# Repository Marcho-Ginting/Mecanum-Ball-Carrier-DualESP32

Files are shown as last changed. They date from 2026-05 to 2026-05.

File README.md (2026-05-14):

# Mecanum-Ball-Carrier-DualESP32

A high-performance mechatronic system utilizing omnidirectional locomotion and a distributed processing architecture for precision robotics tasks.

## 📊 Technical Specifications
* **Architecture:** Dual-ESP32 System (Distributed processing for control and feedback).
* **Locomotion:** 4-wheel drive using Mecanum wheels for 360-degree holonomic movement.
* **Actuation:** 4x High-torque Direct Drive actuators with integrated encoders.
* **PCB:** Custom-manufactured board for power distribution and encoder signal conditioning.

## ⚡ Engineering Highlights
* **Distributed Processing:** Implemented a Dual-ESP32 architecture to isolate real-time motor control and encoder processing from higher-level telemetry and communication, ensuring system stability.
* **Precision Motion Control:** Developed algorithms for Mecanum wheel kinematics, utilizing closed-loop encoder feedback to achieve high-precision velocity and positional tracking.
* **System Integration:** Engineered a custom PCB to consolidate four motor drivers and encoder inputs, optimizing signal integrity and reducing the mechanical footprint of the electronics.
* **Leadership:** Led a cross-disciplinary team of engineers, managing the full development lifecycle from component selection to final system debugging.

## 📂 Repository Structure
* `/logic`: Main logic digital board
* `/pdb`: Driver motor and power distribution board.

## 📷 3D KiCad Render Images

<table style="width:100%">
  <tr>
    <td align="center">
      <br/>
      <b>PDB</b>
    </td>
    <td align="center">
      <br/>
      <b>Logic</b>
    </td>
  </tr>
</table>

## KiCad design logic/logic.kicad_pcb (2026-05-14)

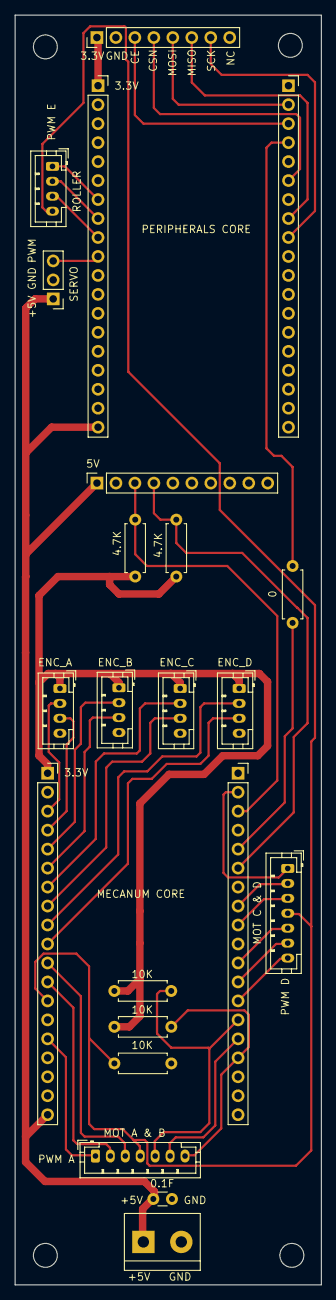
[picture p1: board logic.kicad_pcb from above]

Board: 2 copper layers, 41.0 x 170.0 mm, 22 parts (0 on the bottom side), 38 nets.

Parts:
C_BYPASS1: 0.1uF; C_Disc_D3.0mm_W1.6mm_P2.50mm
J_DRV_SIG1, J_DRV_SIG2: Conn_01x07; JST_PH_B7B-PH-K_1x07_P2.00mm_Vertical
J_DRV_SIG_1: Conn_01x04; JST_PH_B4B-PH-K_1x04_P2.00mm_Vertical
J_IMU1: Conn_01x10_Socket; PinSocket_1x10_P2.54mm_Vertical
J_LEFT_ENC1, J_LEFT_ENC2: Conn_01x04; JST_PH_B4B-PH-K_1x04_P2.00mm_Vertical
J_LEFT_HEADERS1, J_LEFT_HEADERS2: Conn_01x19_Pin; PinSocket_1x19_P2.54mm_Vertical
J_LOGIC1: Screw_Terminal_01x02; TerminalBlock_bornier-2_P5.08mm
J_RF1: Conn_01x08_Pin; PinHeader_1x08_P2.54mm_Vertical
J_RIGHT_ENC1, J_RIGHT_ENC2: Conn_01x04; JST_PH_B4B-PH-K_1x04_P2.00mm_Vertical
J_RIGHT_HEADERS1, J_RIGHT_HEADERS2: Conn_01x19_Pin; PinSocket_1x19_P2.54mm_Vertical
J_SERVO1: Conn_01x03_Pin; PinHeader_1x03_P2.54mm_Vertical
R_JUMPER1: 0; R_Axial_DIN0207_L6.3mm_D2.5mm_P7.62mm_Horizontal
R_PULLUP1, R_PULLUP2: 4.7K; R_Axial_DIN0207_L6.3mm_D2.5mm_P7.62mm_Horizontal
R_PULLUP3, R_PULLUP4, R_PULLUP5: 10K; R_Axial_DIN0207_L6.3mm_D2.5mm_P7.62mm_Horizontal

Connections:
/3.3V_MEC: J_LEFT_ENC1.1, J_LEFT_ENC2.1, J_LEFT_HEADERS1.1, J_RIGHT_ENC1.1, J_RIGHT_ENC2.1, R_PULLUP1.2, R_PULLUP2.2, R_PULLUP3.2, R_PULLUP5.2
/3.3V_PER: J_LEFT_HEADERS2.1, J_RF1.1
/+5V: C_BYPASS1.1, J_IMU1.1, J_LEFT_HEADERS1.19, J_LEFT_HEADERS2.19, J_LOGIC1.1, J_SERVO1.1
/CE: J_RF1.3, J_RIGHT_HEADERS2.3
/CSN: J_RF1.4, J_RIGHT_HEADERS2.6
/ENC_A1: J_LEFT_ENC1.2, J_LEFT_HEADERS1.3
/ENC_A2: J_LEFT_ENC1.3, J_LEFT_HEADERS1.4
/ENC_B1: J_LEFT_ENC2.2, J_LEFT_HEADERS1.5
/ENC_B2: J_LEFT_ENC2.3, J_LEFT_HEADERS1.6
/ENC_C1: J_LEFT_HEADERS1.7, J_RIGHT_ENC1.2
/ENC_C2: J_LEFT_HEADERS1.8, J_RIGHT_ENC1.3
/ENC_D1: J_LEFT_HEADERS1.9, J_RIGHT_ENC2.2
/ENC_D2: J_LEFT_HEADERS1.10, J_RIGHT_ENC2.3
/GND_LOGIC: C_BYPASS1.2, J_IMU1.2, J_LEFT_ENC1.4, J_LEFT_ENC2.4, J_LEFT_HEADERS1.14, J_LEFT_HEADERS2.14, J_LOGIC1.2, J_RF1.2, J_RIGHT_ENC1.4, J_RIGHT_ENC2.4, J_RIGHT_HEADERS1.1, J_RIGHT_HEADERS2.1, J_SERVO1.2, R_PULLUP4.2
/IN_A1: J_DRV_SIG1.3, J_LEFT_HEADERS1.11
/IN_A2: J_DRV_SIG1.2, J_LEFT_HEADERS1.12
/IN_B1: J_DRV_SIG1.5, J_RIGHT_HEADERS1.14, R_PULLUP3.1
/IN_B2: J_DRV_SIG1.6, J_RIGHT_HEADERS1.15
/IN_C1: J_DRV_SIG2.3, J_RIGHT_HEADERS1.9
/IN_C2: J_DRV_SIG2.2, J_RIGHT_HEADERS1.8
/IN_D1: J_DRV_SIG2.5, J_RIGHT_HEADERS1.11
/IN_D2: J_DRV_SIG2.6, J_RIGHT_HEADERS1.12
/IN_E1: J_DRV_SIG_1.3, J_LEFT_HEADERS2.9
/IN_E2: J_DRV_SIG_1.2, J_LEFT_HEADERS2.8
/MISO: J_RF1.6, J_RIGHT_HEADERS2.8
/MOSI: J_RF1.5, J_RIGHT_HEADERS2.2
/PWM_A: J_DRV_SIG1.1, J_LEFT_HEADERS1.15
/PWM_B: J_DRV_SIG1.7, J_RIGHT_HEADERS1.16, R_PULLUP5.1
/PWM_C: J_DRV_SIG2.1, J_RIGHT_HEADERS1.2
/PWM_D: J_DRV_SIG2.7, J_RIGHT_HEADERS1.13
/PWM_E: J_DRV_SIG_1.1, J_LEFT_HEADERS2.7
/PWM_SERVO: J_LEFT_HEADERS2.10, J_SERVO1.3
/SCK: J_RF1.7, J_RIGHT_HEADERS2.9
/SCL: J_IMU1.3, J_RIGHT_HEADERS1.3, R_PULLUP2.1
/SDA: J_IMU1.4, J_RIGHT_HEADERS1.6, R_PULLUP1.1
/STBY: J_DRV_SIG1.4, J_DRV_SIG2.4, J_DRV_SIG_1.4, J_LEFT_HEADERS1.13, R_PULLUP4.1
/UART_MASTER: J_RIGHT_HEADERS2.4, R_JUMPER1.1
/UART_SLAVE: J_RIGHT_HEADERS1.5, R_JUMPER1.2

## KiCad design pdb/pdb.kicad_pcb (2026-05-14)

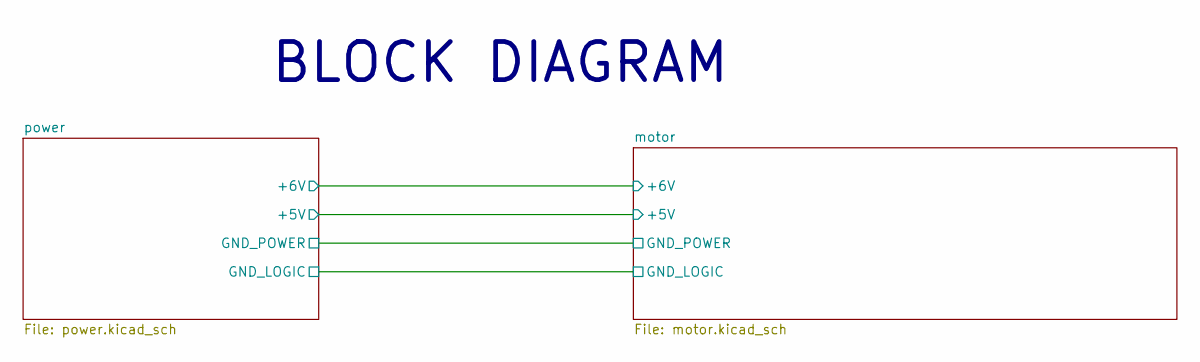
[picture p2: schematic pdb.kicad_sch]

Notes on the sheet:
BLOCK DIAGRAM

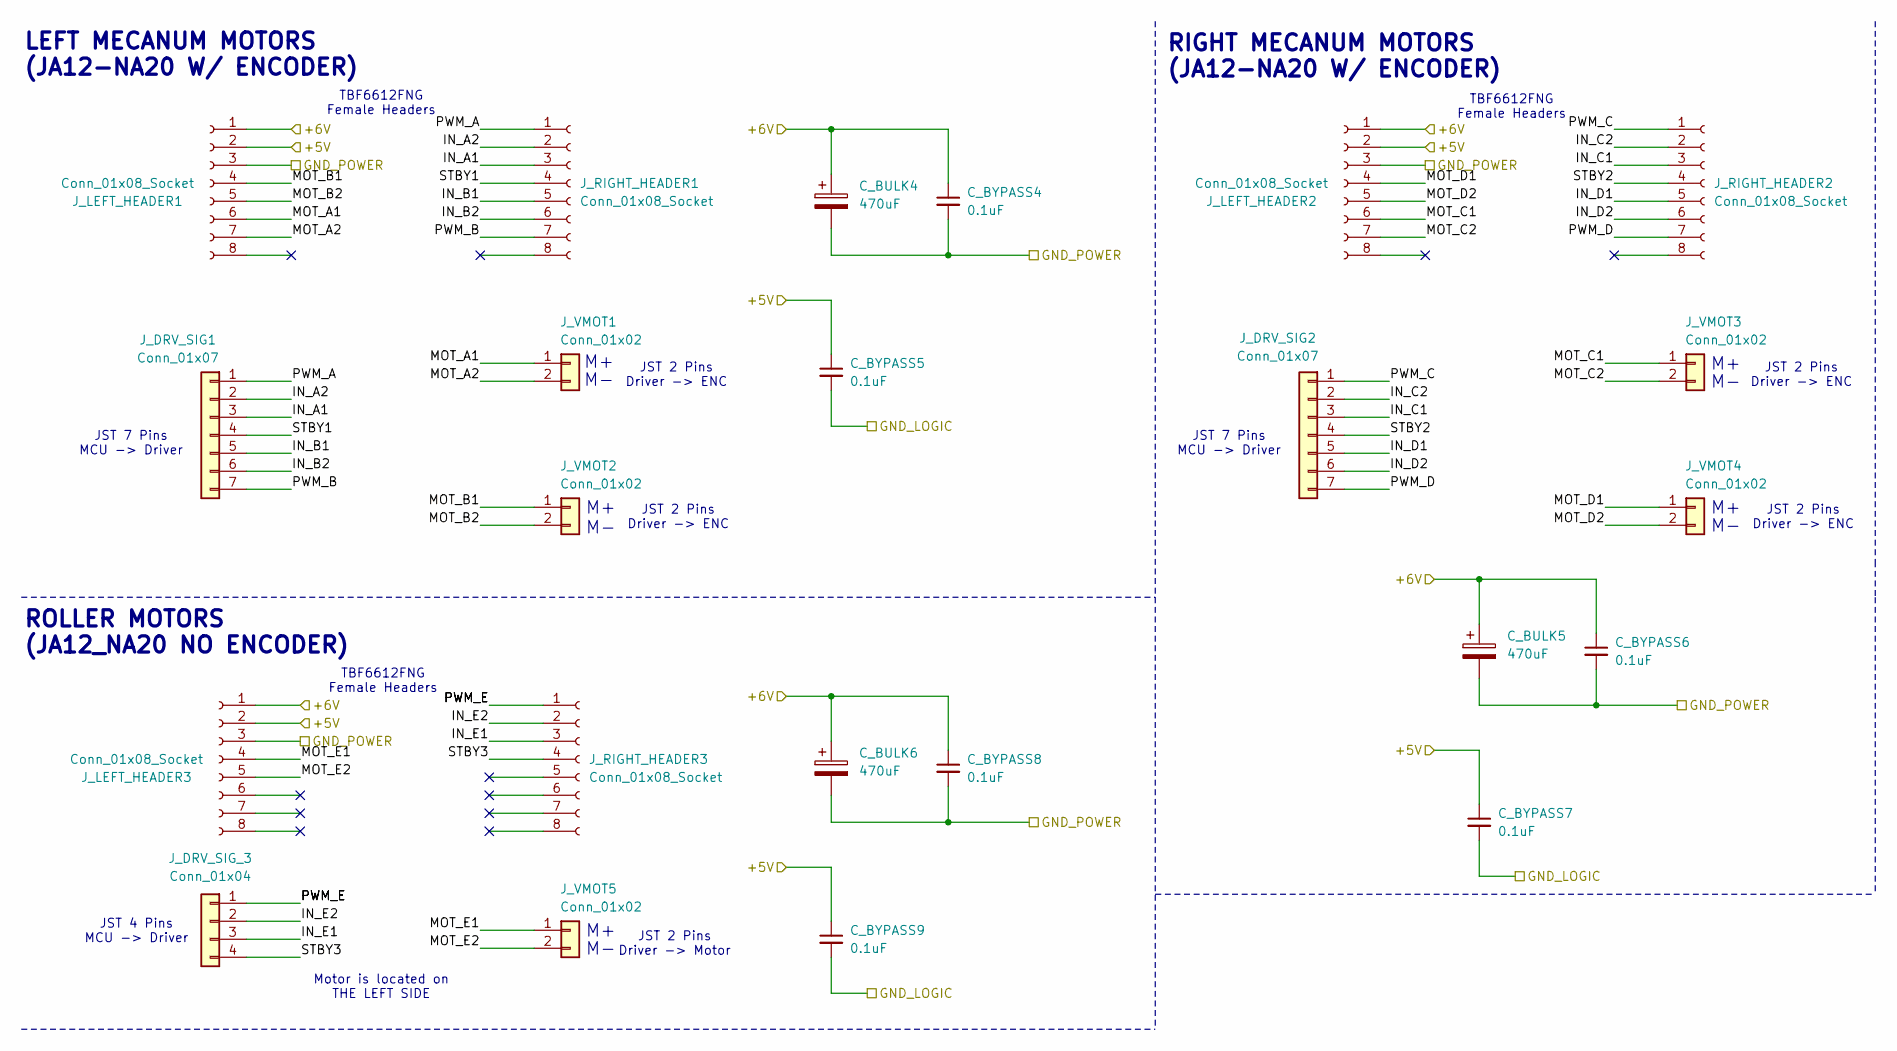
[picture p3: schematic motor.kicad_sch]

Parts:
C_BULK4, C_BULK5, C_BULK6: 470uF; CP_Radial_D10.0mm_P5.00mm
C_BYPASS4, C_BYPASS5, C_BYPASS6, C_BYPASS7, C_BYPASS8, C_BYPASS9: 0.1uF; C_Disc_D3.0mm_W1.6mm_P2.50mm
J_DRV_SIG1, J_DRV_SIG2: Conn_01x07; JST_PH_B7B-PH-K_1x07_P2.00mm_Vertical
J_DRV_SIG_3: Conn_01x04; JST_PH_B4B-PH-K_1x04_P2.00mm_Vertical
J_LEFT_HEADER1, J_LEFT_HEADER2, J_LEFT_HEADER3: Conn_01x08_Socket; PinSocket_1x08_P2.54mm_Vertical
J_RIGHT_HEADER1, J_RIGHT_HEADER2, J_RIGHT_HEADER3: Conn_01x08_Socket; PinSocket_1x08_P2.54mm_Vertical
J_VMOT1, J_VMOT2, J_VMOT3, J_VMOT4, J_VMOT5: Conn_01x02; JST_PH_B2B-PH-K_1x02_P2.00mm_Vertical

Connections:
/motor/+5V: C_BYPASS5.1, C_BYPASS7.1, C_BYPASS9.1, J_LEFT_HEADER1.2, J_LEFT_HEADER2.2, J_LEFT_HEADER3.2; also elsewhere on the board
/motor/+6V: C_BULK4.1, C_BULK5.1, C_BULK6.1, C_BYPASS4.1, C_BYPASS6.1, C_BYPASS8.1, J_LEFT_HEADER1.1, J_LEFT_HEADER2.1, J_LEFT_HEADER3.1; also elsewhere on the board
/motor/GND_LOGIC: C_BYPASS5.2, C_BYPASS7.2, C_BYPASS9.2; also elsewhere on the board
/motor/GND_POWER: C_BULK4.2, C_BULK5.2, C_BULK6.2, C_BYPASS4.2, C_BYPASS6.2, C_BYPASS8.2, J_LEFT_HEADER1.3, J_LEFT_HEADER2.3, J_LEFT_HEADER3.3; also elsewhere on the board
/motor/IN_A1: J_DRV_SIG1.3, J_RIGHT_HEADER1.3
/motor/IN_A2: J_DRV_SIG1.2, J_RIGHT_HEADER1.2
/motor/IN_B1: J_DRV_SIG1.5, J_RIGHT_HEADER1.5
/motor/IN_B2: J_DRV_SIG1.6, J_RIGHT_HEADER1.6
/motor/IN_C1: J_DRV_SIG2.3, J_RIGHT_HEADER2.3
/motor/IN_C2: J_DRV_SIG2.2, J_RIGHT_HEADER2.2
/motor/IN_D1: J_DRV_SIG2.5, J_RIGHT_HEADER2.5
/motor/IN_D2: J_DRV_SIG2.6, J_RIGHT_HEADER2.6
/motor/IN_E1: J_DRV_SIG_3.3, J_RIGHT_HEADER3.3
/motor/IN_E2: J_DRV_SIG_3.2, J_RIGHT_HEADER3.2
/motor/MOT_A1: J_LEFT_HEADER1.6, J_VMOT1.1
/motor/MOT_A2: J_LEFT_HEADER1.7, J_VMOT1.2
/motor/MOT_B1: J_LEFT_HEADER1.4, J_VMOT2.1
/motor/MOT_B2: J_LEFT_HEADER1.5, J_VMOT2.2
/motor/MOT_C1: J_LEFT_HEADER2.6, J_VMOT3.1
/motor/MOT_C2: J_LEFT_HEADER2.7, J_VMOT3.2
/motor/MOT_D1: J_LEFT_HEADER2.4, J_VMOT4.1
/motor/MOT_D2: J_LEFT_HEADER2.5, J_VMOT4.2
/motor/MOT_E1: J_LEFT_HEADER3.4, J_VMOT5.1
/motor/MOT_E2: J_LEFT_HEADER3.5, J_VMOT5.2
/motor/PWM_A: J_DRV_SIG1.1, J_RIGHT_HEADER1.1
/motor/PWM_B: J_DRV_SIG1.7, J_RIGHT_HEADER1.7
/motor/PWM_C: J_DRV_SIG2.1, J_RIGHT_HEADER2.1
/motor/PWM_D: J_DRV_SIG2.7, J_RIGHT_HEADER2.7
/motor/PWM_E: J_DRV_SIG_3.1, J_RIGHT_HEADER3.1
/motor/STBY1: J_DRV_SIG1.4, J_RIGHT_HEADER1.4
/motor/STBY2: J_DRV_SIG2.4, J_RIGHT_HEADER2.4
/motor/STBY3: J_DRV_SIG_3.4, J_RIGHT_HEADER3.4

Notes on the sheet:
ROLLER MOTORS (JA12_NA20 NO ENCODER)
JST 2 Pins Driver -> ENC
LEFT MECANUM MOTORS (JA12-NA20 W/ ENCODER)
JST 7 Pins MCU -> Driver
TBF6612FNG Female Headers
JST 2 Pins Driver -> Motor
JST 4 Pins MCU -> Driver
RIGHT MECANUM MOTORS (JA12-NA20 W/ ENCODER)
Motor is located on THE LEFT SIDE

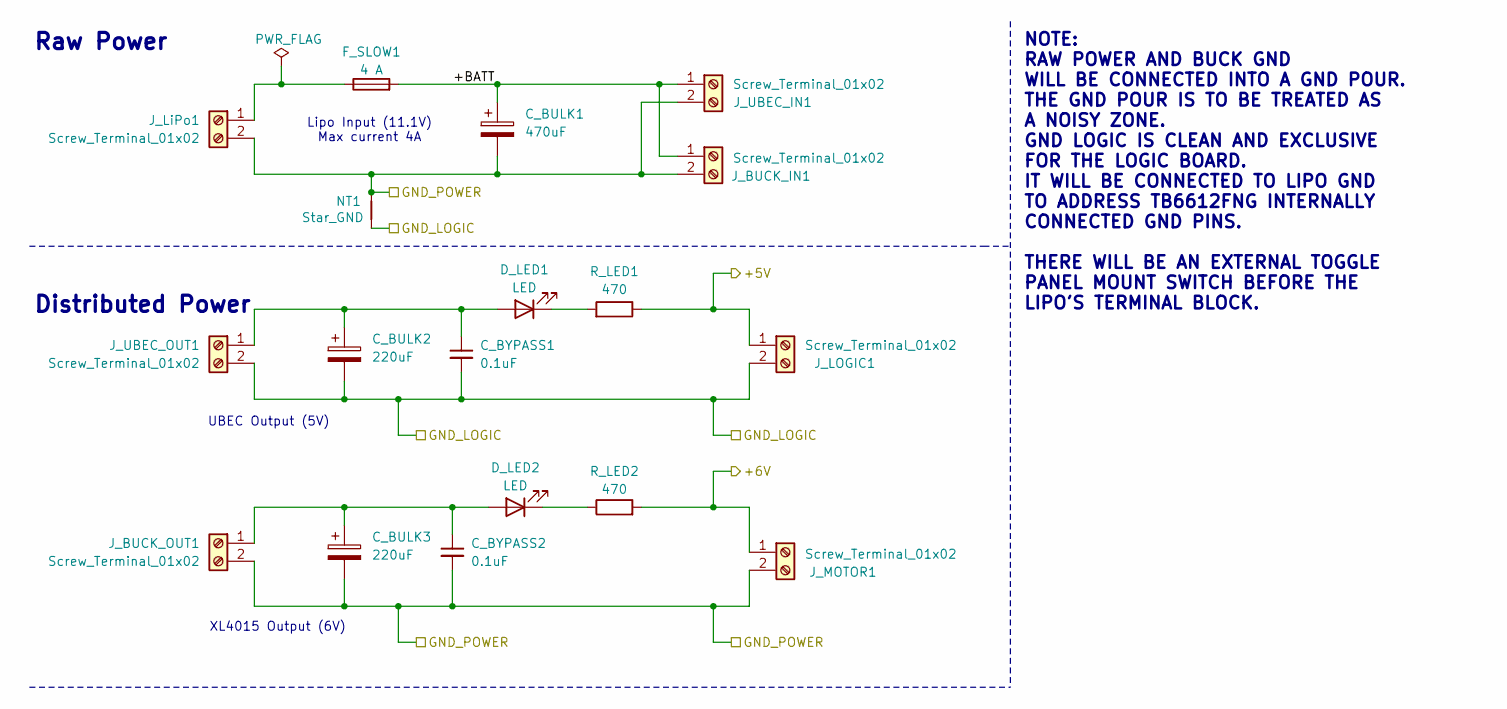
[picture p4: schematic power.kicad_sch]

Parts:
C_BULK1: 470uF; CP_Radial_D10.0mm_P5.00mm
C_BULK2, C_BULK3: 220uF; CP_Radial_D8.0mm_P3.50mm
C_BYPASS1, C_BYPASS2: 0.1uF; C_Disc_D3.0mm_W1.6mm_P2.50mm
D_LED1, D_LED2: LED; LED_D5.0mm_Clear
F_SLOW1: 4 A; Fuseholder_Clip-5x20mm_Bel_FC-203-22_Lateral_P17.80x5.00mm_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
J_BUCK_IN1: Screw_Terminal_01x02; TerminalBlock_bornier-2_P5.08mm
J_BUCK_OUT1: Screw_Terminal_01x02; TerminalBlock_bornier-2_P5.08mm
J_LOGIC1: Screw_Terminal_01x02; TerminalBlock_bornier-2_P5.08mm
J_LiPo1: Screw_Terminal_01x02; TerminalBlock_MetzConnect_Type175_RT02702HBLC_1x02_P7.50mm_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
J_MOTOR1: Screw_Terminal_01x02; TerminalBlock_bornier-2_P5.08mm
J_UBEC_IN1: Screw_Terminal_01x02; TerminalBlock_bornier-2_P5.08mm
J_UBEC_OUT1: Screw_Terminal_01x02; TerminalBlock_bornier-2_P5.08mm
NT1: Star_GND; NetTie-2_THT_Pad1.0mm
R_LED1, R_LED2: 470; R_Axial_DIN0207_L6.3mm_D2.5mm_P7.62mm_Horizontal

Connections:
/motor/+5V: J_LOGIC1.1, R_LED1.1; also elsewhere on the board
/motor/+6V: J_MOTOR1.1, R_LED2.2; also elsewhere on the board
/motor/GND_LOGIC: C_BULK2.2, C_BYPASS1.2, J_LOGIC1.2, J_UBEC_OUT1.2, NT1.1; also elsewhere on the board
/motor/GND_POWER: C_BULK1.2, C_BULK3.2, C_BYPASS2.2, J_BUCK_IN1.2, J_BUCK_OUT1.2, J_LiPo1.2, J_MOTOR1.2, J_UBEC_IN1.2, NT1.2; also elsewhere on the board
/power/+BATT: C_BULK1.1, F_SLOW1.2, J_BUCK_IN1.1, J_UBEC_IN1.1
unnamed: C_BULK2.1, C_BYPASS1.1, D_LED1.2 (A), J_UBEC_OUT1.1
unnamed: D_LED1.1 (K), R_LED1.2
unnamed: C_BULK3.1, C_BYPASS2.1, D_LED2.2 (A), J_BUCK_OUT1.1
unnamed: D_LED2.1 (K), R_LED2.1
unnamed: F_SLOW1.1, J_LiPo1.1

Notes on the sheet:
NOTE: RAW POWER AND BUCK GND WILL BE CONNECTED INTO A GND POUR. THE GND POUR IS TO BE TREATED AS A NOISY ZONE. GND LOGIC IS CLEAN AND EXCLUSIVE FOR THE LOGIC BOARD. IT WILL BE CONNECTED TO LIPO GND TO ADDRESS TB6612FNG INTERNALLY CONNECTED GND PINS. THERE WILL BE AN EXTERNAL TOGGLE PANEL MOUNT SWIT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
UBEC Output (5V)
Raw Power
XL4015 Output (6V)
Distributed Power
Lipo Input (11.1V) Max current 4A

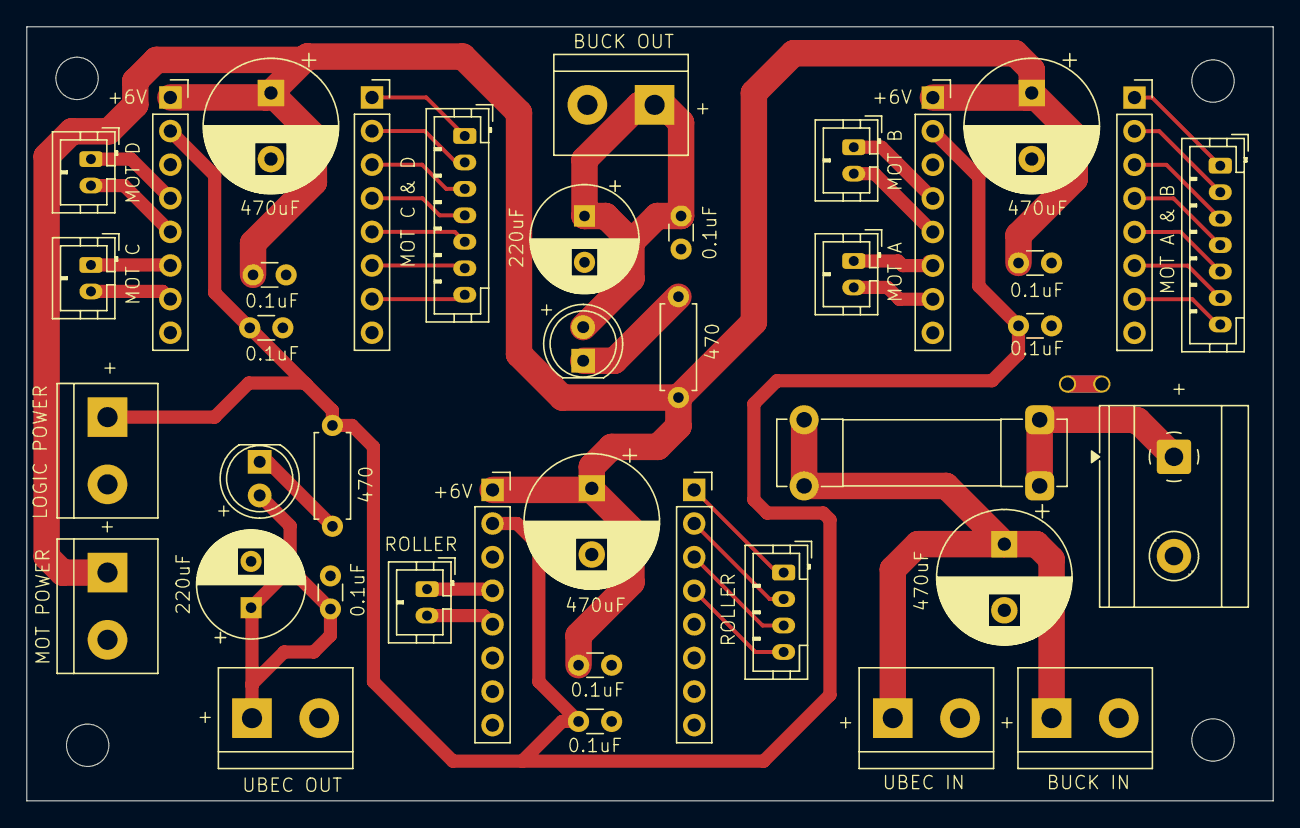
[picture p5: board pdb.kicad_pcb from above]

Board: 2 copper layers, 94.2 x 58.5 mm, 41 parts (0 on the bottom side), 38 nets.
